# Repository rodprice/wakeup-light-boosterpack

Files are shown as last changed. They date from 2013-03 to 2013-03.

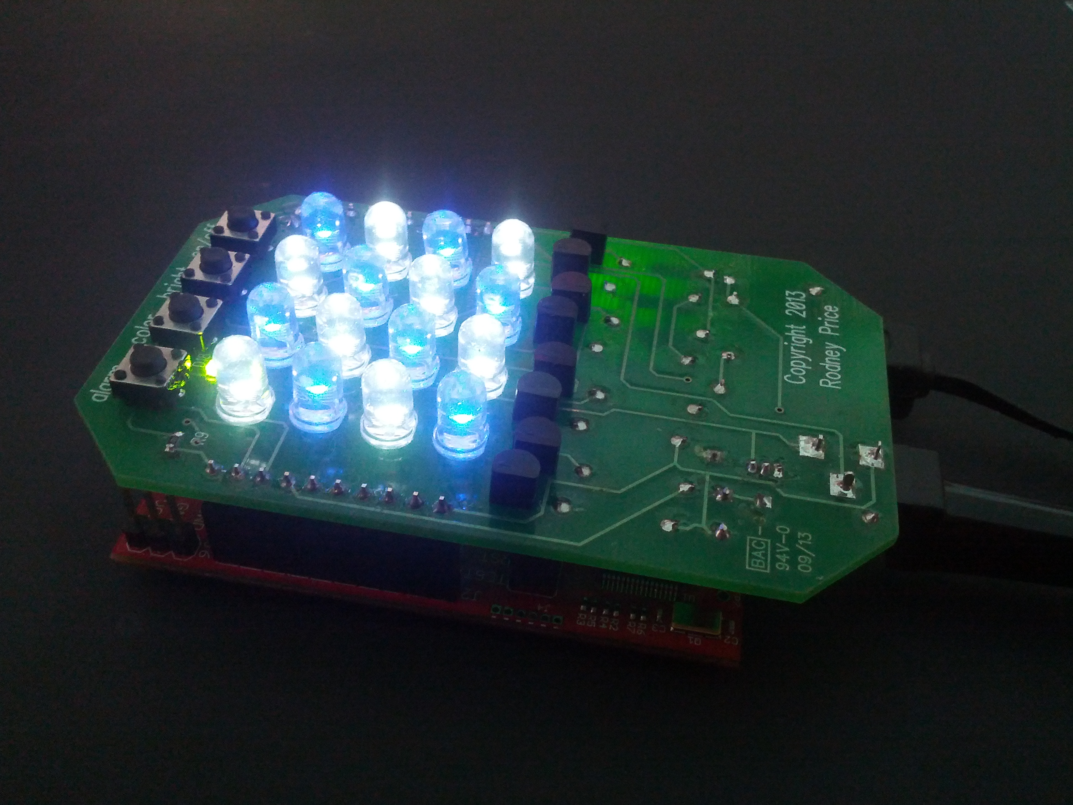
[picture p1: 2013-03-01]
wakeup-light.jpg

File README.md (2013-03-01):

wakeup-light-boosterpack
========================

A boosterpack for Texas Instruments' MSP430 Launchpad platform.

My body doesn't seem to be designed to get out of bed without loud
complaints.  This is especially true in the winter months, when I have
to be out of bed before the sun comes up.  This boosterpack is
designed to help, by tickling light-sensitive cells in the eye that
tell the body to wake up.

Blue light wakes you up?
------------------------

It
[seems](http://gizmodo.com/5701003/blue-lighting-wakes-schoolkids-up)
[so](http://www.dailymail.co.uk/sciencetech/article-1333029/Blue-lighting-trialled-British-school-wake-drowsy-pupils-thing-morning.html)
[1].  In the past two or three years, scientists have found that, in
addition to the rods and cones, the eye has a [third type of
photoreceptor](http://www.nature.com/news/2011/110119/full/469284a.html
"Vision sciene: Seeing without seeing") [2].  Among other things,
these cells send the brain signals about when to sleep and when to
wake up.  They respond to blue light, the bright blue from the sky
that surrounds us outdoors on a sunny day.  They take "rise and shine"
literally: the sun is up, the sky is blue, so wake up!

This boosterpack lets you experiment with adding a little blue light
into your life, even if you are asleep in bed before sunrise, or
working in a room with thick walls separating you from that lovely
blue sky.  It mounts 16 high-intensity LEDs, eight white and eight
blue, which are controlled with an MSP430 Launchpad.  The intensity of
the white lights is controlled with the TA0.1 PWM pin, while the
intensity of the blue lights is controlled with the TA0.2 PWM pin of
the MSP430G2452 chip.

How it works
------------

Code [hosted on
Github](https://github.com/rodprice/wakeup-light-boosterpack) turns
the boosterpack/Launchpad combination into a visual alarm clock of
sorts.  When the alarm "goes off," the light gradually begins to
increase in intensity over the space of about half an hour.  It stays
on for another half hour, long enough for you to get out of bed if
you're going to, then turns itself off.  Four buttons along the top of
the boosterpack allow you to control the lights.  "On/off" does just
what it says: it toggles the lights on and off.  This is what you use
in the morning if you want to turn the lights off without a lot of
fuss.  Holding down the "bright" button goes through a sequence of
four brightness levels.  Release the button when you get to the
maximum brightness level you are comfortable with.  This is the
maximum intensity you will see in the morning.  The "color" button
works similarly: hold it down to cycle through blue light only, white
light only, or both.  Finally, the "alarm" button toggles the alarm
indicator, a small green LED, on and off.  If the indicator light is
on, the alarm will go off in the morning.

The boosterpack gets its power from a 18V wall-mounted plugin power
supply (wall wart).  This powers four strings of four LEDs each.  Each
LED string is controlled with a very simple constant-current sink
built from two general-purpose NPN transistors.  A voltage regulator
on the board generates Vcc at 3.6V for the Launchpad, so you don't
have to keep the Launchpad plugged into a USB port for power.  Just
plug the Launchpad into the boosterpack, plug the wall wart into an
outlet, and connect the two, and you're set.

Except for one thing: setting the time for the alarm to go off.  I've
kept the pinout of the boosterpack compatible with the [43oh OLED
display](http://store.43oh.com/index.php?route=product/product&path=64&product_id=57)
("The Terminal") available at 43oh.com.  You should be able to stack
the OLED boosterpack on top of this one, and use the two buttons on
the OLED boosterpack to set the time and alarm.  I should warn you
that I haven't done this, however.  You'll have to write the code
yourself.

I set the time and alarm myself using the Launchpad USB port, writing
out the time directly in the MSP430 code.  A bit crude, I know, but
this is just experimentation, after all.  I have included a battery
backup in the boosterpack, so that the Launchpad can maintain enough
power to remember the time even when the wall wart is unplugged.  That
way, you can plug the Launchpad/boosterpack combination into your
computer's USB port, set the time and alarm, unplug it, carry it into
your bedroom, and plug it back in without losing the time.  The four
buttons on the boosterpack will give you enough control after that.

Experiences
-----------

I set this boosterpack up in my 8-year-old's bedroom during the month
of February.  The first two mornings, my normally somnolent son
bounded out of bed 15 minutes early, heading right into Mom and Dad's
bedroom.  Since then, it continues to help my son out of bed... just
not in such a forceful fashion.

Your mileage may vary.

A word of caution: blue light isn't always good for you.  Too much,
especially in the absence of other light, can
[damage your eyes](http://www.mdsupport.org/library/hazard.html) [3].
(Be especially careful if you have had cataract surgery.)  At the
wrong time of day, it will mess up your
[circadian rhythm](http://abclocal.go.com/ktrk/story?section=news/health&id=8779461)
(body clock) [4].  And if you have a tendency to migraine headaches,
you
[might not want to use this light](http://news.sciencemag.org/sciencenow/2010/01/11-01.html?etoc
"Why light makes migraines worse") [5] at all.  If in doubt, consult
your doctor.

1. [Blue lighting wakes schoolkids up](http://gizmodo.com/5701003/blue-lighting-wakes-schoolkids-up)
2. [Vision science: Seeing without seeing](http://www.nature.com/news/2011/110119/full/469284a.html)
3. [Artificial Lighting and the Blue Light Hazard](http://www.mdsupport.org/library/hazard.html)
4. [Blue light disrupts ability to sleep, research shows](http://abclocal.go.com/ktrk/story?section=news/health&id=8779461)
5. [Why light makes migraines worse](http://news.sciencemag.org/sciencenow/2010/01/11-01.html?etoc)
6. [Melanopsin](http://en.wikipedia.org/wiki/Melanopsin)

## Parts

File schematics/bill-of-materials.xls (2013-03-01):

Quantity | RefDes | Type | Value | Description | Source | Part number | Price
1 | B1 | CR1025 | 3V | Li-Ion coin cell, 10 mm
1 | B1 | BHX1-1025-SM |  | Battery holder, 10 mm | Digikey |  | 0.396
1 | C1 | Capacitor | 10 nF | Ceramic capacitor
1 | C2 | Capacitor | 100 uF | Electrolytic capacitor
1 | D1 | LED, 5mm | white | 15,000 mcd | Adafruit | ID: 754 | 0.278
1 | D2 | LED, 5mm | white | 15,000 mcd | Adafruit | ID: 754 | 0.278
1 | D3 | LED, 5mm | white | 15,000 mcd | Adafruit | ID: 754 | 0.278
1 | D4 | LED, 5mm | white | 15,000 mcd | Adafruit | ID: 754 | 0.278
1 | D5 | LED, 5mm | blue | 6,000 mcd, 465 nm | Adafruit | ID: 301 | 0.32
1 | D6 | LED, 5mm | blue | 6,000 mcd, 465 nm | Adafruit | ID: 301 | 0.32
1 | D7 | LED, 5mm | blue | 6,000 mcd, 465 nm | Adafruit | ID: 301 | 0.32
1 | D8 | LED, 5mm | blue | 6,000 mcd, 465 nm | Adafruit | ID: 301 | 0.32
1 | D9 | LED, 5mm | white | 15,000 mcd | Adafruit | ID: 754 | 0.278
1 | D10 | LED, 5mm | white | 15,000 mcd | Adafruit | ID: 754 | 0.278
1 | D11 | LED, 5mm | white | 15,000 mcd | Adafruit | ID: 754 | 0.278
1 | D12 | LED, 5mm | white | 15,000 mcd | Adafruit | ID: 754 | 0.278
1 | D13 | LED, 5mm | blue | 6,000 mcd, 465 nm | Adafruit | ID: 301 | 0.32
1 | D14 | LED, 5mm | blue | 6,000 mcd, 465 nm | Adafruit | ID: 301 | 0.32
1 | D15 | LED, 5mm | blue | 6,000 mcd, 465 nm | Adafruit | ID: 301 | 0.32
1 | D16 | LED, 5mm | blue | 6,000 mcd, 465 nm | Adafruit | ID: 301 | 0.32
1 | D17 | 1N4148 |  | small signal diode
1 | D18 | LED 0805 | green | 40 mcd, 570 nm | Mouser | Dialight 598-8170-107F (http://www.mouser.com/Search/ProductDetail.aspx) | 0.072
1 | D19 | LED 0805 | green | 40 mcd, 570 nm | Mouser | Dialight 598-8170-107F (http://www.mouser.com/Search/ProductDetail.aspx) | 0.072
1 | D20 | 1N4148 |  | small signal diode
1 | J1 | Header |  | 10 pin, 0.1" pitch, male
1 | J2 | Header |  | 10 pin, 0.1" pitch, male
1 | J4 | PJ-035C |  | 2.1 mm barrel jack | Adafruit | ID: 373 | 0.95
1 | Q1 | BC549 |  | NPN transistor
1 | Q2 | BC549 |  | NPN transistor
1 | Q3 | BC549 |  | NPN transistor
1 | Q4 | BC549 |  | NPN transistor
1 | Q5 | BC549 |  | NPN transistor
1 | Q6 | BC549 |  | NPN transistor
1 | Q7 | BC549 |  | NPN transistor
1 | Q8 | BC549 |  | NPN transistor
1 | R1 | Resistor | 2.4k | 1/4 watt, metal film
1 | R2 | Resistor | 36 | 1/4 watt, metal film
1 | R3 | Resistor | 2.4k | 1/4 watt, metal film
1 | R4 | Resistor | 36 | 1/4 watt, metal film
1 | R5 | Resistor | 2.4k | 1/4 watt, metal film
1 | R6 | Resistor | 36 | 1/4 watt, metal film
1 | R7 | Resistor | 2.4k | 1/4 watt, metal film
1 | R8 | Resistor | 36 | 1/4 watt, metal film
1 | R9 | Resistor | 220 | SMD 0603
1 | R10 | Resistor | 220 | SMD 0603
1 | R11 | Resistor | 1k | 1/4 watt, metal film
1 | R12 | Resistor | 2.2k | 1/4 watt, metal film
1 | S1 | Pushbutton |  | normally open
1 | S2 | Pushbutton |  | normally open
1 | S3 | Pushbutton |  | normally open
1 | S4 | Pushbutton |  | normally open
1 | U1 | LM317LZ | TL317CLP | voltage regulator
 |  |  |  |  |  |  | 6.274

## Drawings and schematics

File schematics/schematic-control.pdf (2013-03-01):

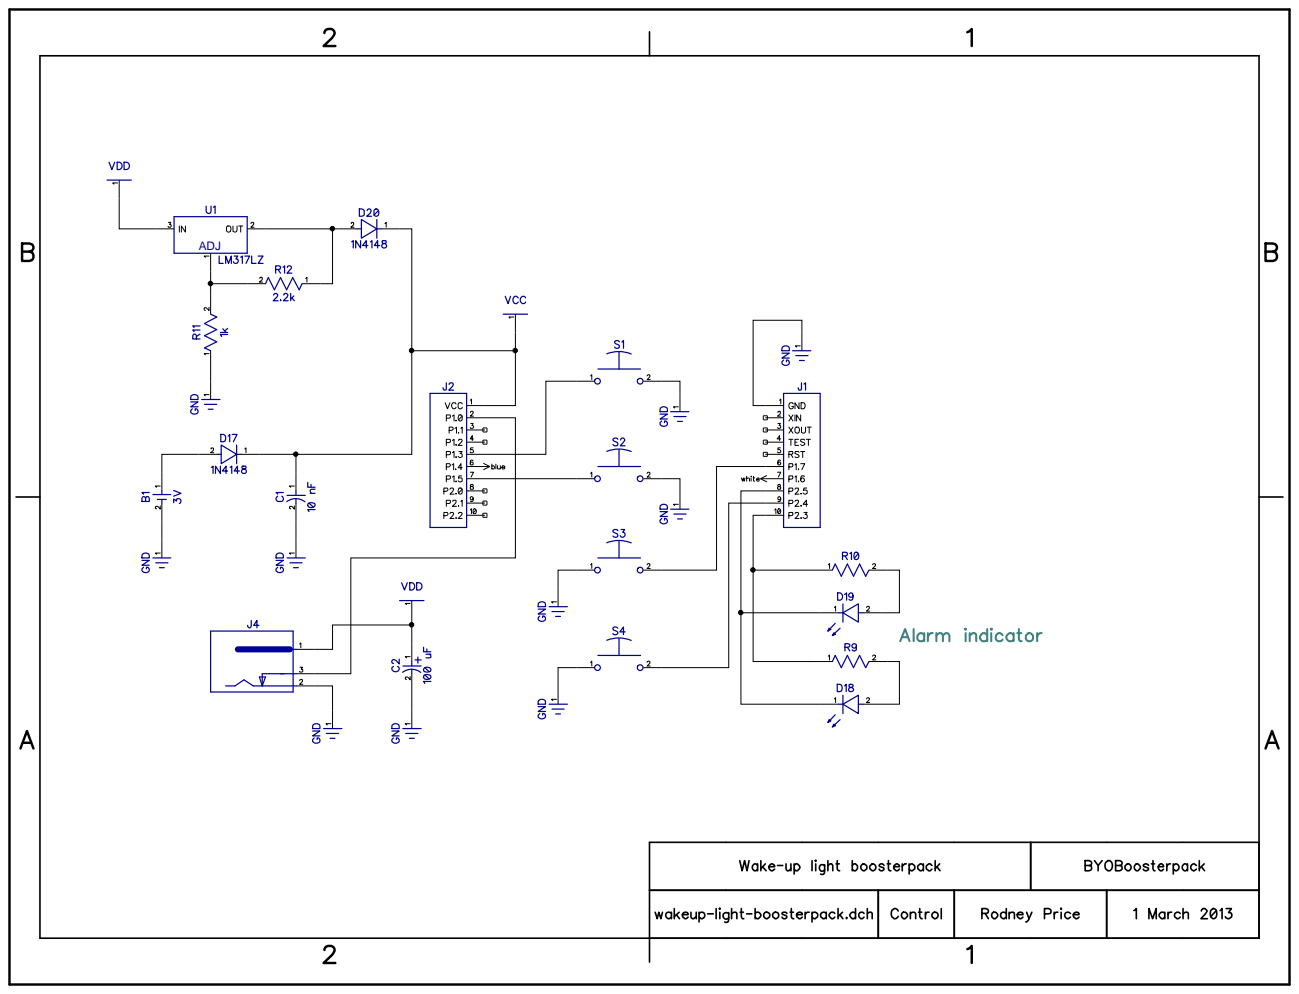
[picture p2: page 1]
ADJ

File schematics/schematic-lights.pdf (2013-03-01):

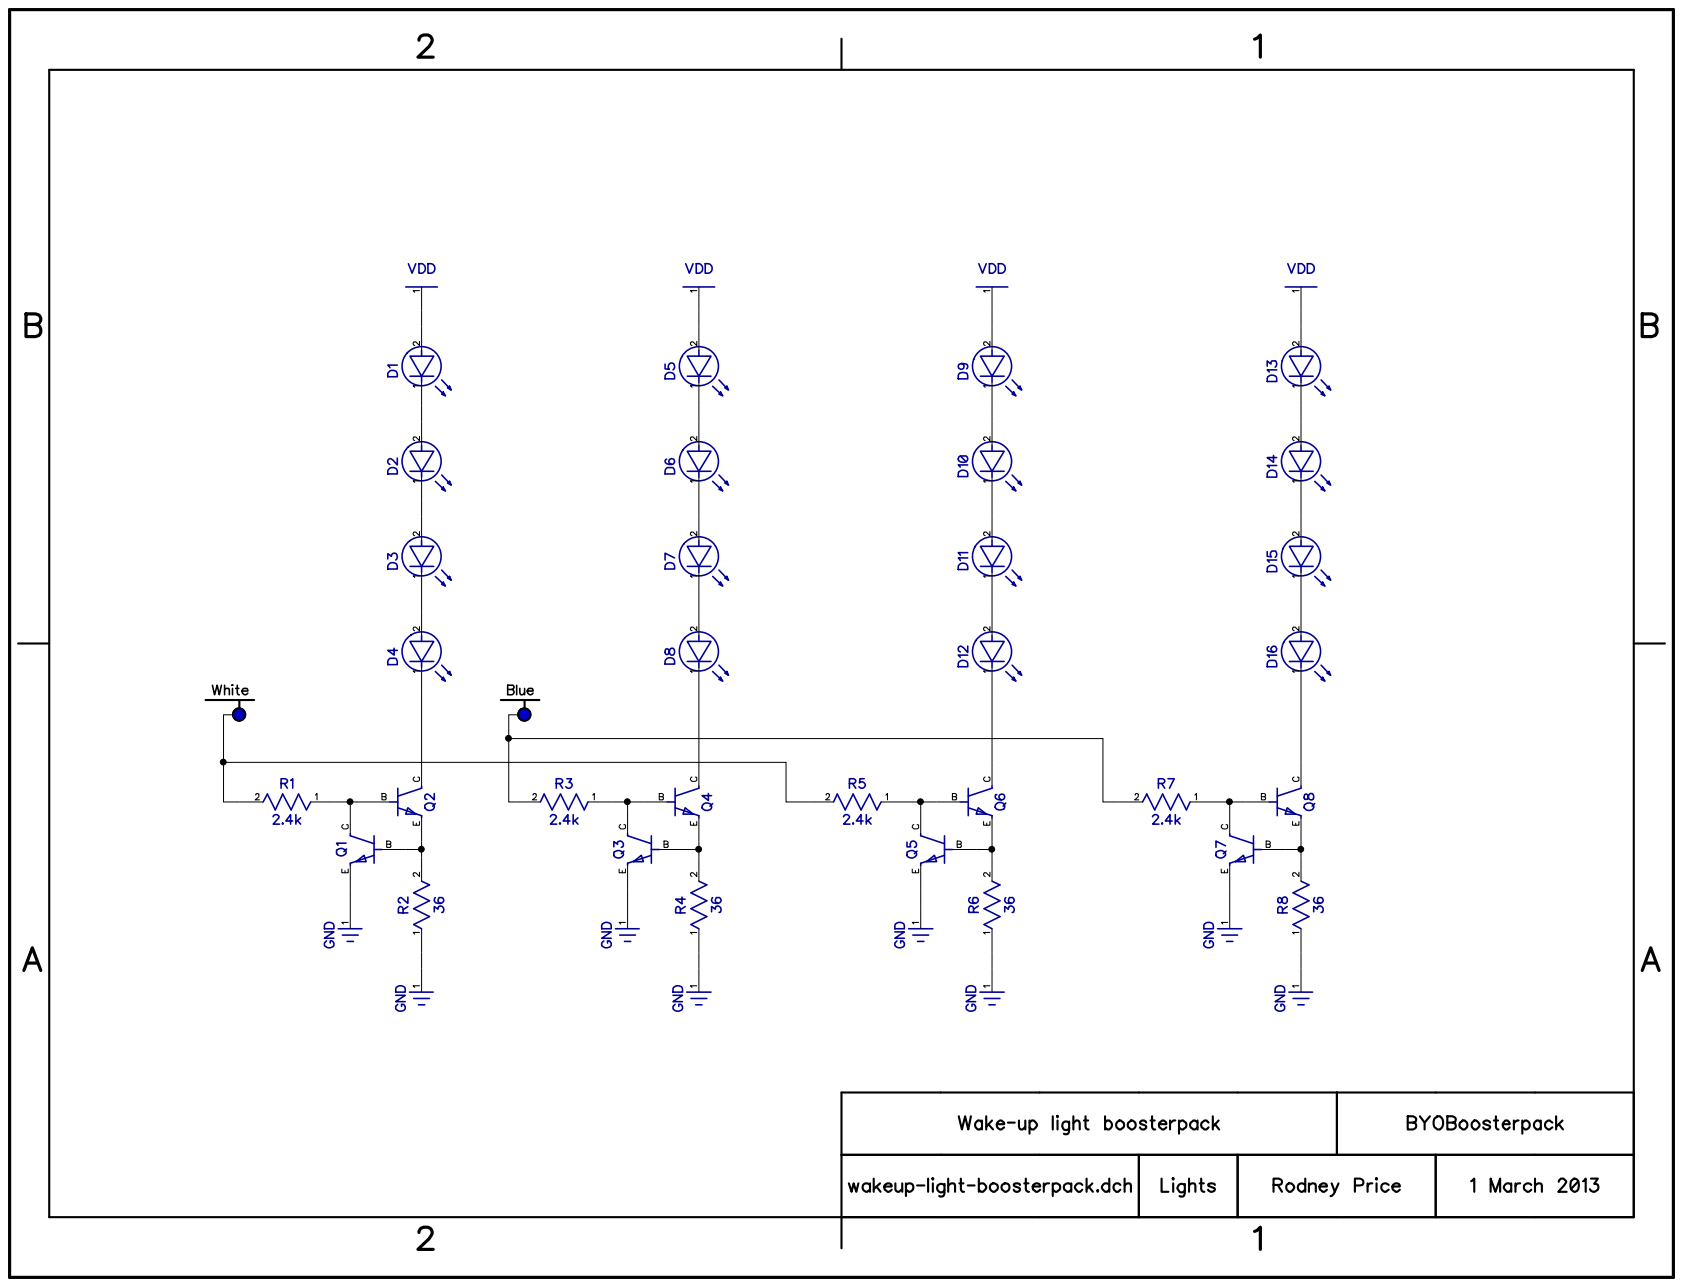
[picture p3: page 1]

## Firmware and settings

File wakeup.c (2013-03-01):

/* 
 * Wake-up light
 * Rodney Price
 */

/* Use -mmcu= flag to specify MCU */
#include <msp430.h>

#define PC r0                   /* program counter */
#define SP r1                   /* stack pointer */
#define SR r2                   /* status register */

#define interrupt(x) void __attribute__((interrupt (x))) 

/* Prototypes */
void initTimerA0(void);
void updateLights(void);
void blink(void);
static void __inline__ delay(register unsigned int);

/************************************************************************
 * Globals
 ************************************************************************/

/* Continuously running counters */
#define TICK_PERIOD 20          /* must be >= 3 */

/* Button de-bouncing parameters */
#define PRESS_THRESHOLD 0x000f
#define RELEASE_THRESHOLD 0xfff0
#define PWM_PERIOD 128

/* Button events */
#define PRESSED 1
#define RELEASED 2
#define LONGPRESS 4
static unsigned int evButton1 = 0; /* change flag for button 1 */
static unsigned int evButton2 = 0; /* change flag for button 2 */
static unsigned int evButton3 = 0; /* change flag for button 3 */
static unsigned int evButton4 = 0; /* change flag for button 4 */

/* Button state */
static unsigned int srButton1 = 0xffff; /* shift register for button 1 */
static unsigned int srButton2 = 0xffff; /* shift register for button 2 */
static unsigned int srButton3 = 0xffff; /* shift register for button 3 */
static unsigned int srButton4 = 0xffff; /* shift register for button 4 */
static unsigned int dbButton1 = 0;    /* debounced state for button 1 */
static unsigned int dbButton2 = 0;    /* debounced state for button 2 */
static unsigned int dbButton3 = 0;    /* debounced state for button 3 */
static unsigned int dbButton4 = 0;    /* debounced state for button 4 */

/* Clock events */
#define DAY 8                    /* the day just changed */
#define HOUR 4                   /* the hour just changed */
#define MINUTE 2                 /* the minute just changed */
#define SECOND 1                 /* the second just changed */
#define TICK 16                  /* the timer tick just changed */
static unsigned int evClock = 0; /* change flag for the clock */

/* Clock state */
typedef struct {
  int ticks;
  unsigned int seconds;
  unsigned int minutes;
  unsigned int hours;
} time_t;
static time_t time;             /* current time */
static time_t alarm;            /* time when lights begin to brighten */

/* System state */
#define ALARM 0                 /* lights are off until the next alarm*/
#define ON 1                    /* lights are on continuously */
static unsigned int state = ALARM;
static unsigned int ostate = ALARM;

/* Light state */
#define NIGHT 3                 /* lights are at dimmest level */
#define DIM 2                   /* lights are dim */
#define NORMAL 1                /* lights are at normal intensity */
#define BRIGHT 0                /* lights are on all the way */
static unsigned int bright  = BRIGHT;

/* Color state */
#define BLUE 1                  /* blue lights are on */
#define WHITE 2                 /* white lights are on */
static unsigned int color  = BLUE | WHITE;

#define INTENSITY_ARRAY_END 179
static int tocks = INTENSITY_ARRAY_END; /* counter for ALARM state */
const unsigned int standard[]  = {83, 59, 35, 11};
const unsigned int intensity[] =
    { 0,   1,   1,   1,   1,   1,   1,   2,   2,   2,   2,   2,
      2,   2,   2,   3,   3,   3,   3,   3,   3,   4,   4,   4,
      4,   4,   5,   5,   5,   6,   6,   6,   7,   7,   8,   8,
      8,   9,  10,  10,  11,  11,  12,  13,  13,  14,  15,  16,
     17,  18,  19,  20,  21,  23,  24,  25,  27,  29,  30,  32,
     34,  36,  38,  40,  43,  45,  48,  51,  54,  57,  60,  64,
     68,  72,  76,  81,  85,  91,  96, 102, 108, 114, 121, 128,
    128, 128, 128, 128, 128, 128, 128, 128, 128, 128, 128, 128,  
    128, 128, 128, 128, 128, 128, 128, 128, 128, 128, 128, 128,  
    128, 128, 128, 128, 128, 128, 128, 128, 128, 128, 128, 128,  
    128, 128, 128, 128, 128, 128, 128, 128, 128, 128, 128, 128,  
    128, 128, 128, 128, 128, 128, 128, 128, 128, 128, 128, 128,  
    128, 128, 128, 128, 128, 128, 128, 128, 128, 128, 128, 128,  
    128, 128, 128, 128, 128, 128, 128, 128, 128, 128, 128, 128,  
     96,  64,  48,  32,  24,  16,  12,   8,   4,   2,   1,   0
    };


int main(void)
{
  WDTCTL = WDTPW + WDTHOLD;     /* stop watchdog timer */
  WDTCTL = WDT_ADLY_1000;       /* make watchdog an interval timer */
  IE1 |= WDTIE;

  /* Basic clock system configuration */
  DCOCTL  = CALDCO_1MHZ;
  BCSCTL1 = CALBC1_1MHZ;
  BCSCTL2 = SELM_0 | DIVM_0 | DIVS_0;
  BCSCTL3 = XCAP1;			// 10 pF crystal caps

  initTimerA0();

  P1OUT = 0;
  /* P1.0 set to ACLK to verify watch crystal oscillation */
  P1DIR  |=  BIT0;
  P1SEL  |=  BIT0;
  P1SEL2 &= ~BIT0;
  /* P1.1 is TXD */
  P1DIR  |=  BIT1;
  P1SEL  &= ~BIT1;
  P1SEL2 &= ~BIT1;
  /* P1.2 is RXD */
  P1DIR  &= ~BIT2;
  P1SEL  &= ~BIT2;
  P1SEL2 &= ~BIT2;
  /* P1.3 is button 1 (upper left) */
  P1OUT  |=  BIT3;
  P1REN  |=  BIT3;
  P1DIR  &= ~BIT3;
  P1SEL  &= ~BIT3;
  P1SEL2 &= ~BIT3;
  /* P1.4 set to TA0.2 is blue light on */
  P1OUT  |=  BIT4;
  P1DIR  |=  BIT4;
  P1SEL  |=  BIT4;
  P1SEL2 |=  BIT4;
  /* P1.5 is button 3 (lower left) */
  P1OUT  |=  BIT5;
  P1REN  |=  BIT5;
  P1DIR  &= ~BIT5;
  P1SEL  &= ~BIT5;
  P1SEL2 &= ~BIT5;
  /* P1.6 set to TA0.1 is white light on */
  P1OUT  &= ~BIT6;
  P1DIR  |=  BIT6;
  P1SEL  |=  BIT6;
  P1SEL2 &= ~BIT6;
  /* P1.7 is button 2 (middle left) */
  P1OUT  |=  BIT7;
  P1REN  |=  BIT7;
  P1DIR  &= ~BIT7;
  P1SEL  &= ~BIT7;
  P1SEL2 &= ~BIT7;

  /* P2.0 - 2.2 are unused */
  P2OUT = 0;
  P2DIR  |=   BIT0 | BIT1 | BIT2;
  P2SEL  &= ~(BIT0 | BIT1 | BIT2);
  P2SEL2 &= ~(BIT0 | BIT1 | BIT2);
  /* P2.3 and P2.5 run the alarm indicator LED */
  P2OUT  &= ~(BIT3 | BIT5);
  P2DIR  |=   BIT3 | BIT5;
  P2SEL  &= ~(BIT3 | BIT5);
  P2SEL2 &= ~(BIT3 | BIT5);
  /* P2.4 is button 4 (far left) */
  P2OUT  |=   BIT4;
  P2REN  |=   BIT4;
  P2DIR  &=  ~BIT4;
  P2SEL  &=  ~BIT4;
  P2SEL2 &=  ~BIT4;
  /* P2.6 - 2.7 are XIN and XOUT */
  P2DIR  &= ~(BIT6 | BIT7);
  P2SEL  |=   BIT6 | BIT7;
  P2SEL2 &= ~(BIT6 | BIT7);

  /* Initialize the real-time clock and alarm */
  time.ticks = 3327;
  time.seconds = 0;
  time.minutes = 29;
  time.hours = 18;
  alarm.ticks = 1170;
  alarm.seconds = 10;
  alarm.minutes = 30;
  alarm.hours = 06;

  /* Event loop */
  while(1) {
    __bis_SR_register(LPM3_bits + GIE);

    /* Button 1 turns the lights on and off. */
    if (evButton1 & PRESSED) {
      if (state == ON) {
        /* Lights out if lights were on */
        state = ALARM;
        tocks = INTENSITY_ARRAY_END;
      } else if (tocks < INTENSITY_ARRAY_END) {
        /* Lights out if alarm is running */
        tocks = INTENSITY_ARRAY_END;
      } else {
        /* Lights on */
        state = ON;
      }
      updateLights();
      evButton1 = 0;
    }

    /* Button 2 sets the maximum brightness. */
    if (evButton2 & PRESSED) {
      /* Show the current brightness value. */
      ostate = state;
      state = ON;
      updateLights();
      evButton2 = 0;
    }
    if (evButton2 & LONGPRESS) {
      /* Set a new brightness value. */
      switch (bright) {
      case NIGHT:
        bright = DIM;
        break;
      case DIM:
        bright = NORMAL;
        break;
      case NORMAL:
        bright = BRIGHT;
        break;
      case BRIGHT:
        bright = NIGHT;
        break;
      }
      updateLights();
      evButton2 = 0;
    }
    if (evButton2 & RELEASED) {
      /* Restore the system state. */
      state = ostate;
      updateLights();
      evButton2 = 0;
    }

    /* Button 3 sets the color. */
    if (evButton3 & PRESSED) {
      /* Show the current color value. */
      ostate = state;
      state = ON;
      updateLights();
      evButton3 = 0;
    }
    if (evButton3 & LONGPRESS) {
      /* Set a new color value. */
      switch (color) {
      case 0:
        color = BLUE;
        break;
      case BLUE:
        color = WHITE;
        break;
      case WHITE:
        color = BLUE | WHITE;
        break;
      case BLUE | WHITE:
        color = BLUE;
        break;
      }
      updateLights();
      evButton3 = 0;
    }
    if (evButton3 & RELEASED) {
      /* Restore the system state. */
      state = ostate;
      updateLights();
      evButton3 = 0;
    }

    /* Button 4 "arms" the alarm */
    if (evButton4 & PRESSED) {
      P2OUT ^= BIT3;
      evButton4 = 0;
    }

    /* Real-time clock */
    if (evClock & SECOND) {
      if ((alarm.seconds == time.seconds) && 
          (alarm.minutes == time.minutes) && 
          (alarm.hours   == time.hours)) {
        /* Start the timer for the lights */
        if ((state == ALARM) && (P2OUT & BIT3)) { /* fix: incorporate alarm indicator into state variable */
          tocks = 0;
          updateLights();
          evClock = 0;
        }
      }
    }
    if (evClock & TICK) {
      if (tocks < INTENSITY_ARRAY_END) {
        tocks++;
        updateLights();
      }
      evClock = 0;
    }
  }
}

void initTimerA0() {
  TA0CTL   = TASSEL_1		// use ACLK
           | ID_0			// divide by 1
           | MC_1   		// up mode
           | TACLR;         // start counter from 0
  TA0CCTL0 = OUTMOD_4;	    // 50% duty cycle
  TA0CCR0  = PWM_PERIOD;    // 256 Hz update rate
  TA0CCTL1 = OUTMOD_7;	    // set/reset PWM mode
  TA0CCR1  = 0;	            // white lights off
  TA0CCTL2 = OUTMOD_7;	    // set/reset PWM mode
  TA0CCR2  = 0;	            // blue lights off
  TA0CTL  |= TAIE;          // turn on interrupts
}

void blink() {
  /* blink the lights */
  unsigned int tmp1, tmp2;

  tmp1 = TA0CCR1;
  tmp2 = TA0CCR2;
  if (color & WHITE)
    TA0CCR1 = intensity[standard[bright]];
  if (color & BLUE)
    TA0CCR2 = intensity[standard[bright]];
  delay(40000);
  TA0CCR1 = tmp1;
  TA0CCR2 = tmp2;
}

void updateLights() {
  /* Update the blue lights */
  if (color & BLUE) {
    /* System state is not OFF and color blue is on */
    if (state) 
      TA0CCR2 = intensity[ standard[bright] ];
    else
      TA0CCR2 = intensity[tocks] >> (2*bright);
  } else {
    TA0CCR2 = 0;
  }
  /* Update the white lights */
  if (color & WHITE) {
    /* System state is not OFF and color white is on */
    if (state) 
      TA0CCR1 = intensity[ standard[bright] ];
    else
      TA0CCR1 = intensity[tocks] >> (2*bright);
  } else {
    TA0CCR1 = 0;
  }
}


unsigned int 
test_button(unsigned int *srButton, 
            unsigned int *dbButton, 
            unsigned int *duration,
            unsigned int bit) {
  /* Shift state of button into its shift register */
  *srButton >>= 1;
  if (((P1IN & bit & 0x00ff) && (BIT8 & bit)) || 
      ((P2IN & bit & 0x00ff) && (BIT9 & bit)))
    *srButton |= BITF;
  if (*dbButton) {
    /* Button state is down */
    if (*srButton >= RELEASE_THRESHOLD) {
      /* Low to high transition */
      *dbButton = 0;
      return RELEASED;
    }
    if (*srButton <= PRESS_THRESHOLD) {
      /* Look for long press event */
      (*duration)++;
      if ((*duration & 0x00ff) == 0)
        return (*duration & 0xff00) | LONGPRESS;
    } else {
      /* Button is still bouncing */
      *duration = 0;
      return 0;
    }
  } else {
    /* Button state is up */
    if (*srButton <= PRESS_THRESHOLD) {
    /* High to low transition */
      *duration = 0;
      *dbButton = 1;
      return PRESSED;
    }
  }
  /* No change */
  return 0;
}

interrupt(TIMER0_A1_VECTOR) debouncer() {
  /* Check button state every 4 ms */
  static unsigned int duration1 = 0;
  static unsigned int duration2 = 0;
  static unsigned int duration3 = 0;
  static unsigned int duration4 = 0;
  switch (TAIV) {
  case 0xA:
    evButton1 = test_button(&srButton1, &dbButton1, &duration1, BIT8 | BIT7);
    evButton2 = test_button(&srButton2, &dbButton2, &duration2, BIT8 | BIT5);
    evButton3 = test_button(&srButton3, &dbButton3, &duration3, BIT8 | BIT3);
    evButton4 = test_button(&srButton4, &dbButton4, &duration4, BIT9 | BIT4);
    if ( evButton1 || evButton2 || evButton3 || evButton4 )
      __bic_SR_register_on_exit(LPM3_bits);
    break;
  }
}

interrupt(WDT_VECTOR) WDT_ISR(void) {
  static int ticker = TICK_PERIOD;
  /* Update timer ticks */
  evClock = 0;
  ticker--;
  if (ticker <= 0) {
    ticker = TICK_PERIOD;
    time.ticks++;
    evClock |= TICK;
  }
  /* Update seconds, minutes, hours */
  time.seconds += 1;
  evClock |= SECOND;
  if (time.seconds == 60) {
    time.seconds = 0;
    time.minutes += 1;
    evClock |= MINUTE;
    if (time.minutes == 60) {
      time.minutes = 0;
      time.hours += 1;
      evClock |= HOUR;
      if (time.hours == 24) {
        time.hours = 0;
        time.ticks = 0;
        evClock |= DAY | TICK;
      }
    }
  }
  __bic_SR_register_on_exit(LPM3_bits);
}

// Delay Routine from mspgcc help file
static void __inline__ delay(register unsigned int n)
{
  __asm__ __volatile__ (
  "1: \n"
  " dec %[n] \n"
  " jne 1b \n"
        : [n] "+r"(n));
}

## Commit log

2013-03-01 Update for contest submission.
    [Board.gbr, BoardOutline.gbr, Bottom.gbr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]
2013-03-02 Native diptrace schematics + netlist + p-cad format.
    [wakeup-light-boosterpack-pcad-format.sch]
